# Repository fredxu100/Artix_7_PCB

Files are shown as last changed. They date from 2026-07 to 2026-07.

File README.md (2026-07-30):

# High-Speed 8-Layer XC7A FPGA PCB

<p align="center">
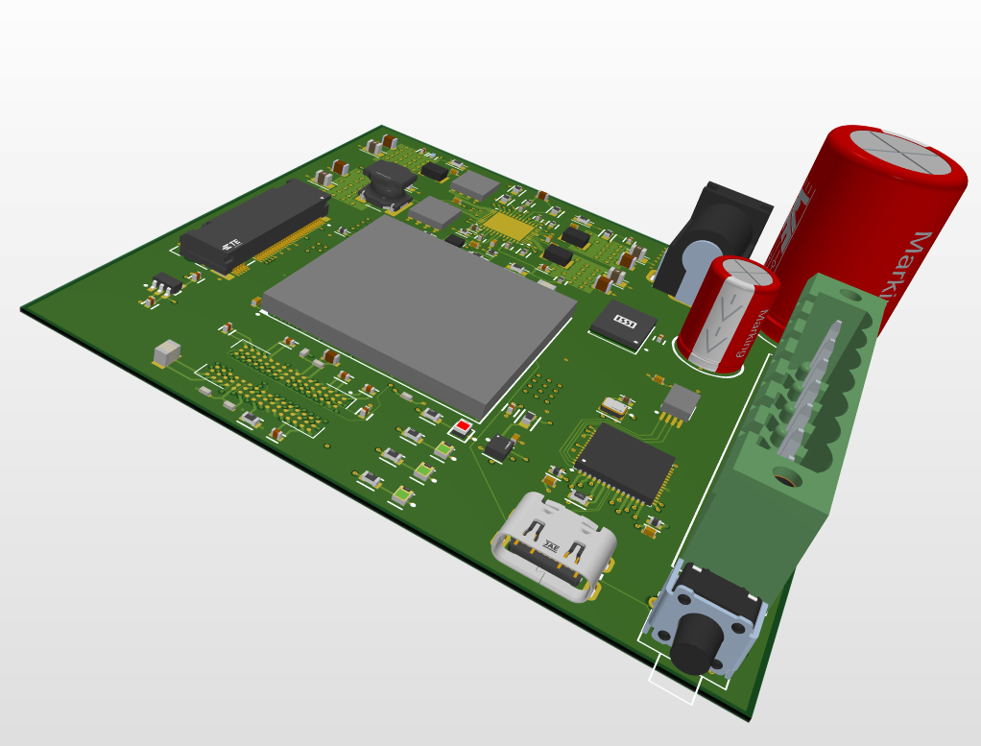
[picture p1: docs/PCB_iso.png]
PCB 3D Render
  
</p>

## Overview
This repository contains the complete design files, manufacturing outputs, and stackup documentation for an 8-layer high-speed PCB designed around an XC7A FPGA 

## Technical Specifications

| Parameter | Specification |
| :--- | :--- |
| **Layer Count** | 8 Layers (SIG1 - GND - SIG2 - GND - PWR - SIG3 GND - SIG4) |
| **Board Dimensions** | 3000 mil × 3000 mil |
| **Impedance Control** | 50 Ω Single-Ended, 90/100 Ω Differential Pairs |
| **Primary CAD Tool** | Altium Designer |

---

### Stackup & Controlled Impedance Architecture
8-layer stackup was implemented with solid reference planes directly adjacent to primary high-speed signal layers:

* **L1 (Top):** Components, general signal lines, fanout
* **L2 (GND1):** Solid reference ground plane
* **L3 (Inner 1):** High speed signal routing
* **L4 (GND1):** Solid reference ground plane
* **L5 (Power):** Split power planes for 1, 1.35, 1.8, and 3.3 V
* **L6 (Inner 2):** High speed signal routing
* **L7 (GND2):** Solid reference ground plane
* **L8 (Bottom):** High-density breakout signals & secondary routing, decoupling capacitors

<p align="center">
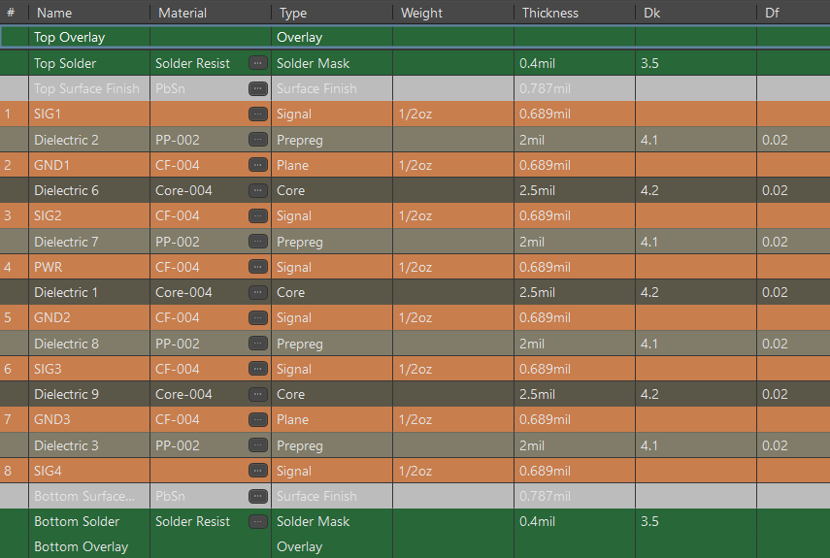
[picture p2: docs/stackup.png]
Layer Stackup Specs
  
</p>

## Repository Structure

```text
systolic-array-matrix-processor-pcb/
├── README.md                      <-- Project landing page
├── docs/                          <-- Documentation & visual renders
├── fabrication_pack/              <-- Gerber X2, NC Drill, and IPC-2581 outputs
└── altium_files/                  <-- Raw Altium (.PrjPcb, .SchDoc, .PcbDoc, .OutJob)

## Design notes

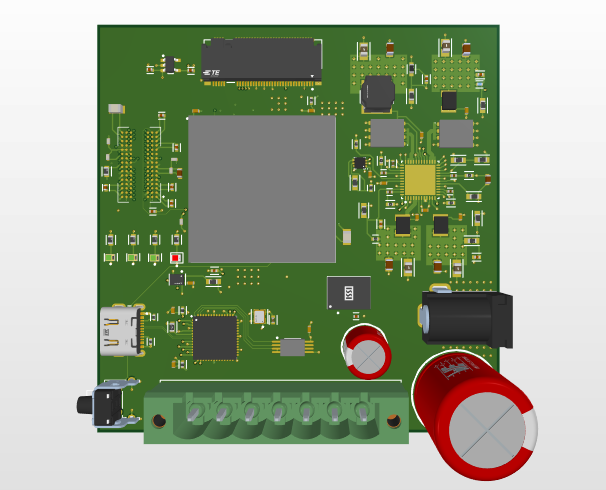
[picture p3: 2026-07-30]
docs/PCB_top.png

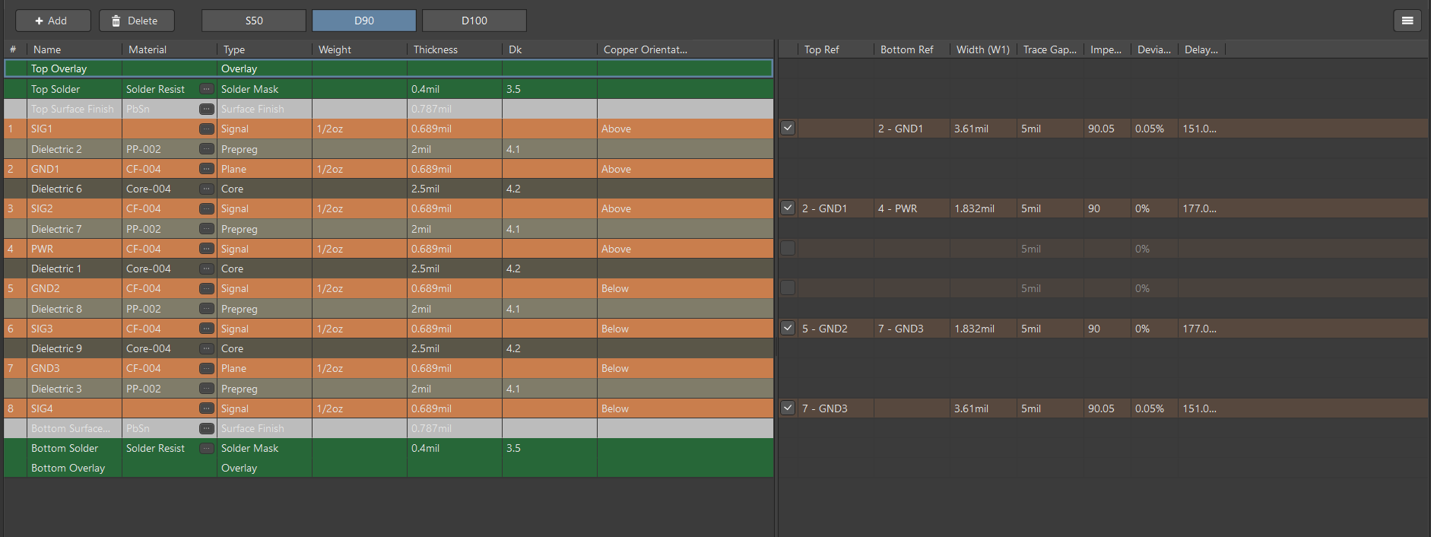
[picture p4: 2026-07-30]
docs/D90.png

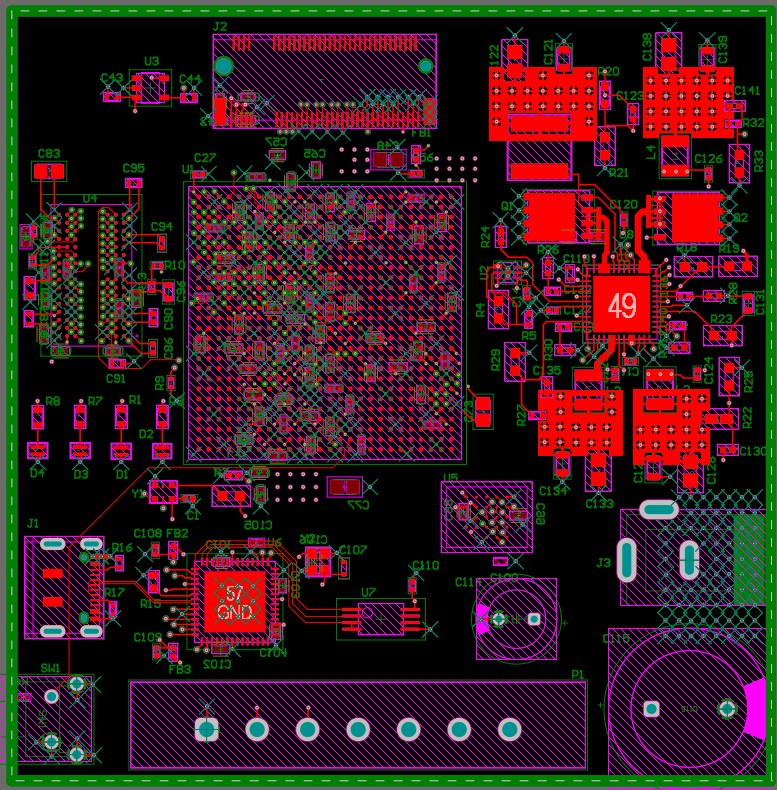
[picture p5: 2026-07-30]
docs/PCB_SIG1.png

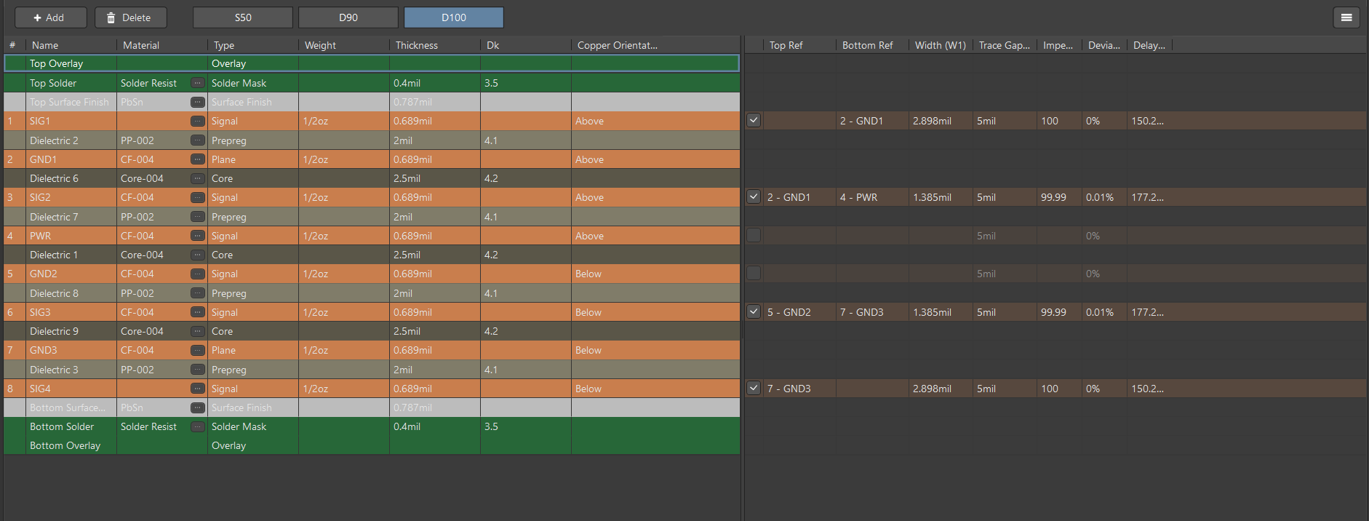
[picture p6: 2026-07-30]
docs/D100.png

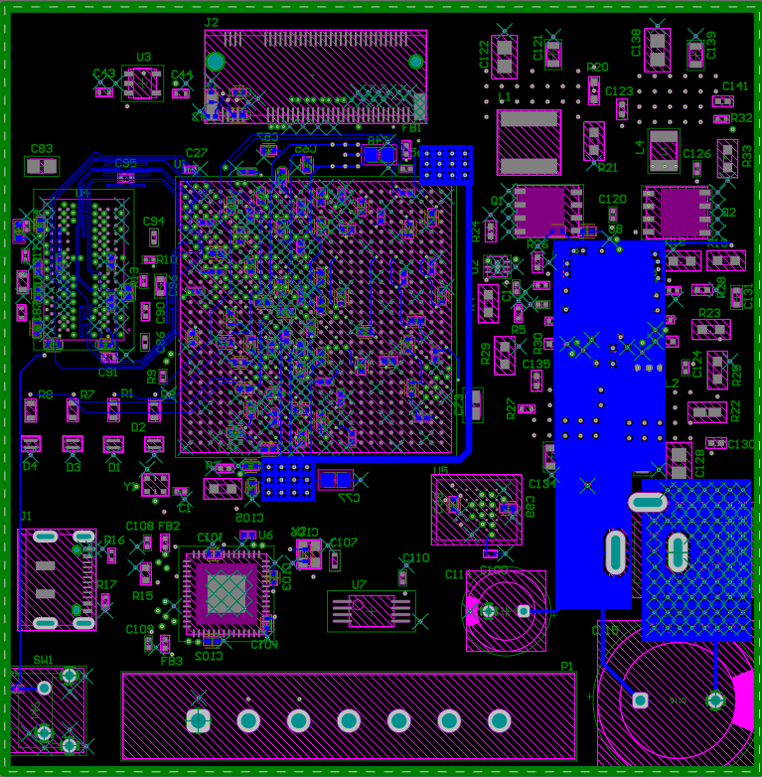
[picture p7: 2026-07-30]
docs/PCB_SIG4.png

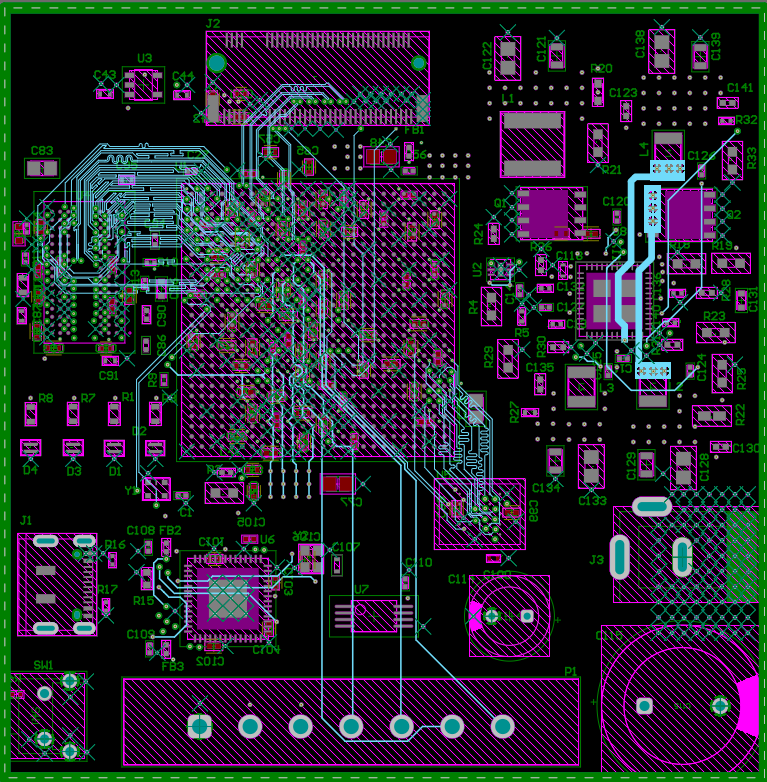
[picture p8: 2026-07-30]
docs/PCB_SIG3.png

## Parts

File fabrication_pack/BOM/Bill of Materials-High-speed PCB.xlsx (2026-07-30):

Line # | Name | Description | Designator | Revision ID | Revision State | Revision Status | Quantity | Manufacturer 1 | Manufacturer Part Number 1 | Manufacturer Lifecycle 1 | Supplier 1 | Supplier Part Number 1 | Supplier Unit Price 1 | Supplier Subtotal 1
 | 0.1 uF | Chip Capacitor, 0.1 uF, +/- 5%, 16 V, 0402 (1005 Metric), Chip Capacitor, 0.1 uF, +/- 5%, 16 V, 0402 (1005 Metric), 0.1-1 ohm ESR, 15 MHz-1nH ESL | C1, C2, C3, C12, C13, C14, C19, C20, C21, C22, C27, C28, C33, C34, C35, C49, C50, C51, C56, C60, C64, C68, C72, C78, C79, C84, C88, C92, C105, C108, C109, C110, C119, C120, C124, C125, C126, C127, C142 |  | Unknown server |  | 39 | Murata | GRM155R71C104JA88D | Not Recommended for New Design | Mouser | 81-GRM155R71C104JA8D | 0.024 | 0.936
 | 220 nF | Cap Ceramic 220nF 25V X7R 20% Pad SMD 0402 +125°C Automotive T/R | C4, C5, C10, C11, C16, C18, C23, C24, C29, C31, C36, C39, C42, C47, C52, C55, C59, C61, C67, C69, C76, C89, C93, C118 |  | Unknown server |  | 24 | TDK | CGA2B3X7R1E224M050BB | Volume Production | Mouser | 810-CGA2B3X7R1E224MB | 0.108 | 2.59
 | 470 nF | Chip Multilayer Ceramic Capacitors for General Purpose, 0402, 0.47uF, X7R, 15%, 20%, 10V | C6, C9, C17, C25, C32, C37, C41, C46, C53, C58, C62, C66, C70, C75, C81, C86, C90, C94, C99, C102, C112, C117 |  | Unknown server |  | 22 | Murata | GRM155R71A474ME01D | Volume Production | Mouser | 81-GRM155R71A474ME1D | 0.164 | 3.61
 | 1 uF, 1uF | Ceramic Capacitor for Automotive 1uF ±20% 10VDC X7S 0402 Paper T/R | C7, C8, C15, C26, C30, C38, C40, C43, C44, C45, C54, C57, C63, C65, C71, C74, C82, C87, C91, C95, C98, C101, C104, C113, C116 |  | Unknown server |  | 25 | Murata | GCM155C71A105ME38D | Volume Production | Newark | GCM155C71A105ME38D | 0.041 | 1.03
 | 10 uF |  | C48, C73, C77, C83 |  | Unknown server |  | 4 | KYOCERA AVX | 0805ZG106ZAT2A | Volume Production | DigiKey | 478-KGM21AV51A106ZUDKR-ND | 0.3 | 1.2
 | 150 nF | Ceramic Capacitor for Automotive 150nF ±20% 16VDC X7R 0402 Paper T/R | C80, C85, C100, C103, C111 |  | Unknown server |  | 5 | Murata | GCM155R71C154ME02D | Volume Production
 | Capacitor 1µF +/-40% 50V 0603 | Chip Capacitor, 1µF +/-40%, 50V, 0603, Thickness 1 mm | C96, C97, C131 |  | Unknown server |  | 3 | Samsung Electro-Mechanics | CL10A105KB8NNNC | Volume Production | Newark | CL10A105KB8NNNC | 0.113 | 0.339
 | 18 pF | Cap Ceramic 18pF 50V C0G 5% Pad SMD 0402 +125°C Automotive T/R | C106, C107 |  | Unknown server |  | 2 | TDK | CGA2B2C0G1H180J050BA | Volume Production | Newark | CGA2B2C0G1H180J050BA | 0.099 | 0.198
 | 330 uF |  | C114 |  | Unknown server |  | 1 | Wurth Elektronik | 860080574007 | Volume Production | DigiKey | 732-9099-1-ND | 0.27 | 0.27
 | 47 uF | Cap, 47Uf, 400V, Alu Elec, Radial Rohs Compliant: Yes | C115 |  | Unknown server |  | 1 | Wurth Elektronik | 860241380015 | Volume Production | Mouser | 710-860241380015 | 4.93 | 4.93
 | Capacitor 22µF +/-40% 16V 0805 | Chip Capacitor, 22µF +/-40%, 16V, 0805, Thickness 1.45 mm, 5-50 mOhm, 0.5-2 nH | C121, C129, C134, C139 |  | Unknown server |  | 4 | Murata | GRM219R61C226ME15L | Volume Production | Conrad | 3425158 | 0.15962 | 0.63847
 | 10uF | CL21 Series 0805 10uF 25V ±10% Tolerance X6S Multilayer Ceramic Chip Capacitor, 5-50 mOhm, 0.5-2 nH | C122, C128, C133, C138 |  | Unknown server |  | 4 | Samsung Electro-Mechanics | CL21X106KAYNNNE | Volume Production
 | 47 pF | Ceramic Capacitor 47pF ±5% 100VDC C0G 0402 Paper T/R | C123, C130, C135, C141 |  | Unknown server |  | 4 | Murata | GQM1555C2A470JB01D | Volume Production | Arrow Electronics | GQM1555C2A470JB01D | 0.3841 | 4.99
 | 2.2n | C0402 2,200 pF C0G 0.02 25 V | C132, C136, C137, C140 |  | Unknown server |  | 4 | Yageo Group | C0402C222G3GACTU | Volume Production | Mouser | 80-C0402C222G3GACTU | 1.03 | 4.12
 | CAL, READY, DONE | LED LUXEON Z GREEN 530NM 2SMD | D1, D3, D4 |  | Unknown server |  | 3 | Lumileds | LXZ1-PM01 | Volume Production | DigiKey | 1416-1057-6-ND | 4.01 | 12.03
 | ERR | LED LUXEON Z RED 633NM 2MSD | D2 |  | Unknown server |  | 1 | Lumileds | LXZ1-PD01 | Volume Production | Mouser | 997-LXZ1PD01 | 4.01 | 4.01
 | 120Ω @ 100MHz | Chip Ferrite Bead, 0402, 120Ω @ 100MHz, 0.09Ω, 25%, 1.3A | FB1, FB2, FB3 |  | Unknown server |  | 3 | Murata | BLM15PD121SN1D | Volume Production | DigiKey | 490-5203-6-ND | 0.1 | 0.3
 | DX07S016JA1R1500 | CONN RCP USB2.0 TYP C 24P SMD RA | J1 |  | Unknown server |  | 1 | JAE Electronics | DX07S016JA1R1500 | Volume Production | DigiKey | 670-DX07S016JA1R1500CT-ND | 1.7 | 1.7
 | 1-2199119-5 | CONN M.2 FEMALE 67POS 0.020 GOLD | J2 |  | Unknown server |  | 1 | TE Connectivity | 1-2199119-5 | Volume Production | Mouser | 571-1-2199119-5 | 2.08 | 2.08
 | KLDX-0202-B | 3 Conductor Power Jack, 2 break 2 aux contacts | J3 |  | Unknown server |  | 1 | Kycon | KLDX-0202-B | Volume Production | DigiKey | 2092-KLDX-0202-B-ND | 0.77 | 0.77
 | 1.3 uH | Shielded Wirewound Inductor 1.3uH 30% 4A 20.8mΩ SMD | L1 |  | Unknown server |  | 1 | TAIYO YUDEN | NR6045T1R3N | Obsolete
 | 2.2 uH | Power Ind, 2.2UH, 4.1A, Shielded, 1210 Rohs Compliant: Yes | L2, L3, L4 |  | Unknown server |  | 3 | Wurth Elektronik | 74479332257222 | New Product | Mouser | 710-74479332257222 | 0.52 | 1.56
 | 691318700007 | Terminal Block, 5.00MM Pitch, Close Vertical Pcb Header, Flanges, 7 Pins | P1 |  | Unknown server |  | 1 | Wurth Elektronik | 691318700007 | Volume Production
 | BSC080N03MS G | N-Channel OptiMOS 3 M-Series Power-MOSFET, 30 V VDS, 53 A ID, -55 to 150 degC, PG-TDSON-8-1, Reel, Green | Q1, Q2 |  | Unknown server |  | 2 | Infineon | BSC080N03MSGATMA1 | Obsolete | Mouser | 726-BSC080N03MSG | 1.54 | 3.08
 | 240 | 240Ω ±1% 0.1W 0603 Thick Film Chip Resistor AEC-Q200 compliant | R1, R3, R7, R8, R12 |  | Unknown server |  | 5 | Stackpole Electronics | RMCF0603FG240R | Volume Production | Avnet | RMCF0603FG240R | 0.0019 | 19
 | 10 k | RES 10kΩ 5.00% 0.2W 0603 | R2, R4, R18, R19, R21, R23, R25, R29, R33 |  | Unknown server |  | 9 | Yageo Group | AC0603JR-7W10KL | Volume Production | Mouser | 603-AC0603JR-7W10KL | 0.021 | 0.21
 | 5k | RES SMD 5K OHM 1% 1/16W 0402 | R5 |  | Unknown server |  | 1 | Yageo Group | RC0402FR-075KL | Volume Production | Mouser | 603-RC0402FR-075KL | 0.1 | 0.1
 | 4.7k |  | R6, R9 |  | Unknown server |  | 2 | Bourns | CR0402-JW-472GLF | Volume Production | Mouser | 652-CR0402-JW-472GLF | 0.006 | 0.06
 | 1k |  | R10, R11, R13, R14 |  | Unknown server |  | 4 | Vishay | CRCW04021K00FKEDHP | Volume Production | Mouser | 71-CRCW04021K00FKEDH | 0.046 | 0.46
 | 12 kΩ | CRGCQ0603 12KΩ 1% ±100ppm/°C 75V | R15 |  | Unknown server |  | 1 | TE Connectivity | CRGCQ0603F12K | Volume Production | Arrow Electronics | CRGCQ0603F12K | 0.004 | 0.004
 | 5.1kΩ | 5.1kΩ ±1% 0.063W, 1/16W Chip Resistor 0402 (1005 Metric) Moisture Resistant Thin Film | R16, R17 |  | Unknown server |  | 2 | KOA Speer | RN73R1ETTP5101F25 | Volume Production | Mouser | 660-RN73R1ETP5101F25 | 0.2 | 0.4
 | 2.49k | RES SMD 2.49K OHM 0.1% 1/10W | R20 |  | Unknown server |  | 1 | Yageo Group | RT0603BRE072K49L | Volume Production | DigiKey | YAG4686DKR-ND | 0.1 | 0.1
 | 6.81k | 6.81kΩ ±1% 0.125W 0603 High Power Anti-Sulfur Thin Film Chip Resistor | R22 |  | Unknown server |  | 1 | Stackpole Electronics | RNCP0603FTD6K81 | Volume Production | DigiKey | RNCP0603FTD6K81CT-ND | 0.1 | 0.1
 | 31.6k | 31.6kΩ ±1% 0.063W 0402 Thick Film Chip Resistor AEC-Q200 compliant | R24 |  | Unknown server |  | 1 | Stackpole Electronics | RMCF0402FT31K6 | Volume Production | Mouser | 708-RMCF0402FT31K6 | 0.1 | 0.1
 | 1.82k | RES Thick Film, 1.82kΩ, 1%, 0.063W, 100ppm/°C, 0402 | R26, R28, R30, R31 |  | Unknown server |  | 4 | Vishay | CRCW04021K82FKED | Volume Production | Mouser | 71-CRCW0402-1.82K-E3 | 0.02 | 0.2
 | 12.7k | RP73P 0402 12.7KΩ 0.1W 25ppm/°C 0.10% 50V | R27 |  | Unknown server |  | 1 | TE Connectivity | RP73PF1E12K7BTD
 | 30.9k | 30.9kΩ ±1% 0.1W Chip Resistor 0402 Thick Film AEC-Q200 Qualified | R32 |  | Unknown server |  | 1 | KOA Speer | RK73H1ELTP3092F | Volume Production
 | FPGA_RESET_SW | Tactile Switch, 0.05A, 12Vdc, 160Gf, Tht Rohs Compliant: Yes | SW1 |  | Unknown server |  | 1 | Wurth Elektronik | 431256058716 | Volume Production | DigiKey | 431256058716-ND | 0.35 | 0.35
 | XC7A100T-2LFGG676E | Artix-7 FPGA, 300 User I/Os, 8 GTP, 676-Ball BGA, Speed Grade 2L, Extended Grade, Pb-Free | U1 |  | Unknown server |  | 1 | Xilinx | XC7A100T-2LFGG676E | Volume Production
 | LTC3025IDC-2#TRMPBF | 500 mA Micropower VLDO Linear Regulator, 1.4 to 5.5 V Vin, 1.2 V Vout, 6-pin SON (DC6-6), -40 to 125 degC, Pb-Free, Mini Tape and Reel | U2 |  | Unknown server |  | 1 | Analog Devices | LTC3025IDC-2#TRMPBF | Volume Production | Mouser | 584-C3025IDC-2TRMPBF | 5.22 | 5.22
 | LM4132EMF-3.0/NOPB | Precision Low Dropout Voltage Reference, 5-pin SOT-23, Pb-Free | U3 |  | Unknown server |  | 1 | Texas Instruments | LM4132EMF-3.0/NOPB | Volume Production | DigiKey | 296-48864-1-ND | 3.04 | 3.04
 | MT41K256M16TW-107:P |  | U4 |  | Unknown server |  | 1
 | IS25WX064-JHLE | IS25WX064-JHLE Octal Flash 64Mbit 8M X 8bit SPI 1.8V 6ns 24-Pin TFBGA | U5 |  | Unknown server |  | 1 | ISSI | IS25WX064-JHLE | Volume Production
 | FT2232H-56Q-REEL | USB Bridge, USB to UART,FIFO USB 2.0 UART, FIFO Interface 56-VQFN (8x8) | U6 |  | Unknown server |  | 1
 | 93LC46B/ST | 1K, 64x16-bit, 2.5V Microwire Serial EEPROM, 8-Pin TSSOP, Commercial Temperature | U7 |  | Unknown server |  | 1 | Microchip | 93LC46B/ST | Volume Production | DigiKey | 93LC46B/ST-ND | 0.35 | 0.35
 | ADP5054ACPZ-R7 | IC REG CTRLR BUCK 48LFCSP | U8 |  | Unknown server |  | 1 | Analog Devices | ADP5054ACPZ-R7 | Volume Production | Arrow Electronics | ADP5054ACPZ-R7 | 13.47 | 13.47
 | ASDMPLV-200.000MHZ-LR-T | MEMS Oscillator 200MHz ±25ppm LVDS 2.25V~3.6V 6-SMD 2.5mm x 2mm | Y1 |  | Unknown server |  | 1 | Abracon | ASDMPLV-200.000MHZ-LR-T | Volume Production | Mouser | 815-ASDMPLV-200-LR-T | 4.2 | 4.2
 | ABM10AIG-12.000MHZ-4Z-T3 | Crystal 12MHz ±30ppm 10pF SMD-4 2.5mm x 2mm Automotive | Y2 |  | Unknown server |  | 1 | Abracon | ABM10AIG-12.000MHZ-4Z-T3 | Volume Production | DigiKey | 535-13360-6-ND | 0.49 | 0.49

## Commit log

2026-07-30 Create README.md for PCB project documentation
    Added detailed project documentation including specifications, design highlights, and repository structure.
2026-07-30 Update PCB title and image references in README
2026-07-30 pcb iso
2026-07-30 schematic pdf
